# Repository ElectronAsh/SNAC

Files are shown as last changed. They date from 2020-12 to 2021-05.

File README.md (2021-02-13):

# SNAC
Accessory converter for MiSTer, by blue212

Serial Native Accessory Converter

SNAC is general purpose level shifter for use with MiSTer. It can be used to power 5v devices and it will safely convert any logic between the 3v3(MiSTer) and 5 device. It will be used mostly for 5v controllers and other peripherals.

The SNAC connects to the User port(formerly Serial I/O port) of the IO board on Mister. I recommend a male to female usb3 extension cable between them.

The SNAC is available in 2 versions the only difference being the connector on the controller side(USB3 or HDMI). Various adapters can then be plugged into that connector. I made various adapter PCCBs for use with the USB3 verrsion.

Becasue the SNAC connects to the User port the peripheral connects to the GPIO of the MiSTer, this bypasses all layers the normal usb controllers use. So it's very much like having a controller port for the original system. One benefit of this is that most weird peripherals should work with their cores(like Lightguns etc) which most normal usb converters either don't or can't do. One downside to bypassing the layers is the you can't controle the OSD.

*A mod to the IO board is needed if you want to use SEGA peripherals. A possible IO board revision in the future may fix this requirement.

-TODO detail the needed mod

-Updates

Changed the partslist to use a different part for the male USB connector.

Uxcell a19032000ux0260 instead of Wuerth 692112030100

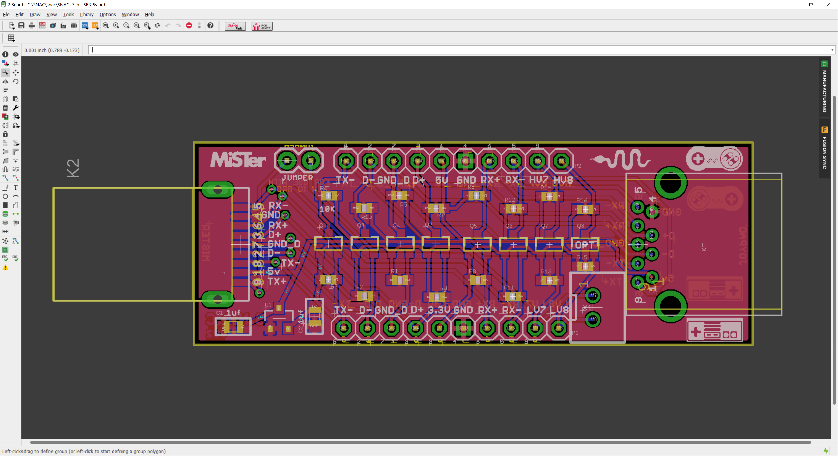
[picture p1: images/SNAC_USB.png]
SNAC to "USB"


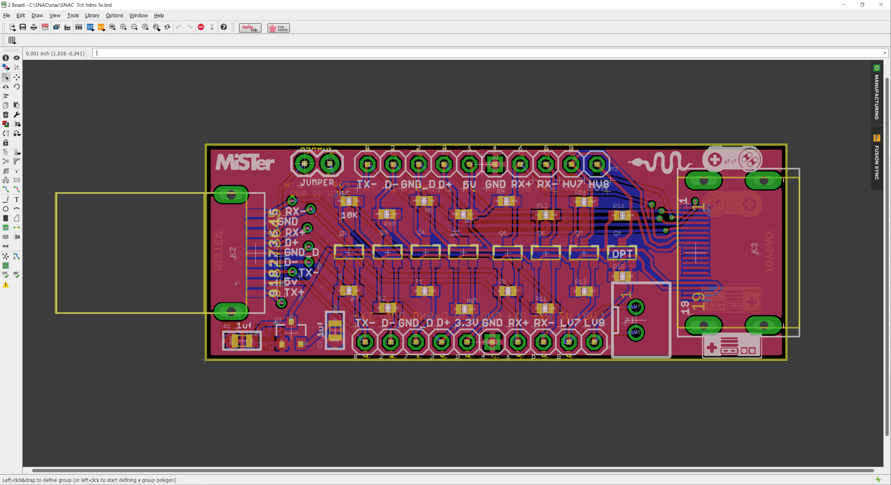
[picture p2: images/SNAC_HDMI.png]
SNAC to "HDMI"


Combined SNES versions, and SMS DB9 version added by ElectronAsh.

#Both SNES versions, and the SMS DB9 version are UNTESTED.
Please do not build until they are confirmed working.

Version with JST XH for the USER IO connection, and PCB meant for a specific housing.
You can find the housing on eBay, using the search term "enclosure 90x70x28mm"

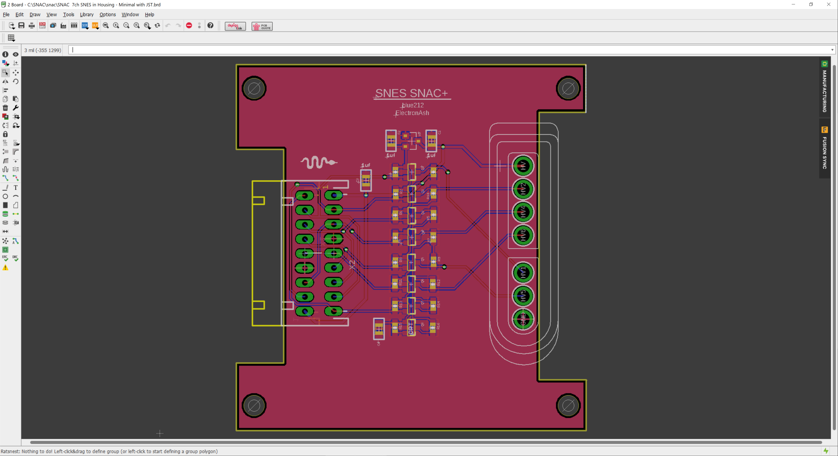
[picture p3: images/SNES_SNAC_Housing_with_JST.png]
SNAC with SNES Socket


The 3D Glasses driver circuit is from e-panorama...
<https://www.epanorama.net/circuits/sega3d.html>

The circuit has been tested on the SMS core now, but it needs a charge pump circuit added, to boost the LCD drive voltage to around 10 Volts.
Without that, the LCDs don't darken enough, and the ghosting is quite severe.

I tested the circuit by powering the CD4030 chip with 10V from a bench PSU. 
(That should ONLY be done if you completely isolate that 10V from the 5V pin on the USER PORT, otherwise it will damage the DE10 Nano.)

EDIT: A charge pump circuit has been added to both the DB9 and dongle version of the 3D Glasses adapter now.
This is currently UNTESTED until more PCBs arrive.

The dongle was tested with the Asus VR-100G LCD shutter glasses, and a JVC monitor.
The frequency of the oscillator that drives the LCDs doesn't seem to have any particular sweet spot for reduction ghosting, but the circuit generally works fine.

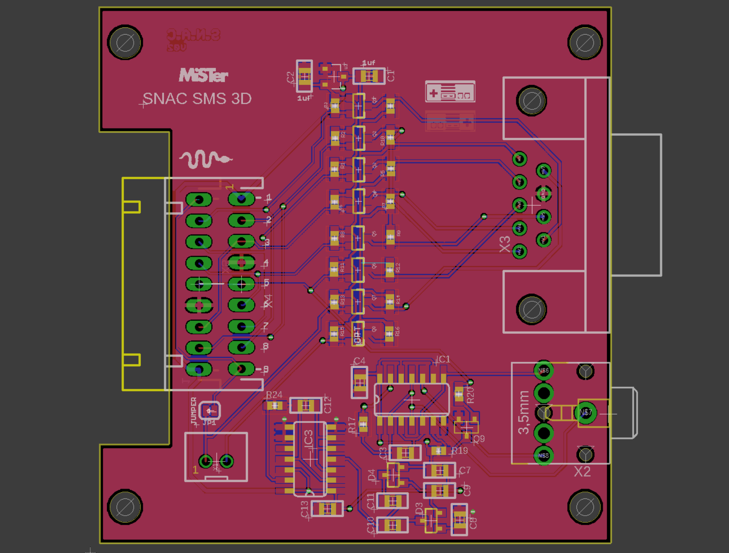
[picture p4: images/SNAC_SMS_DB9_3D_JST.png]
SNAC to SMS DB9 with 3D Glasses driver, JST version


The standalone dongle version of the 3D Glasses driver is for people who don't mind using the SMS core with a USB joypad, and just want the 3D glasses option.
(in which case, both SMS buttons will obviously work fine when mapping from a USB joypad, or USB keyboard.)

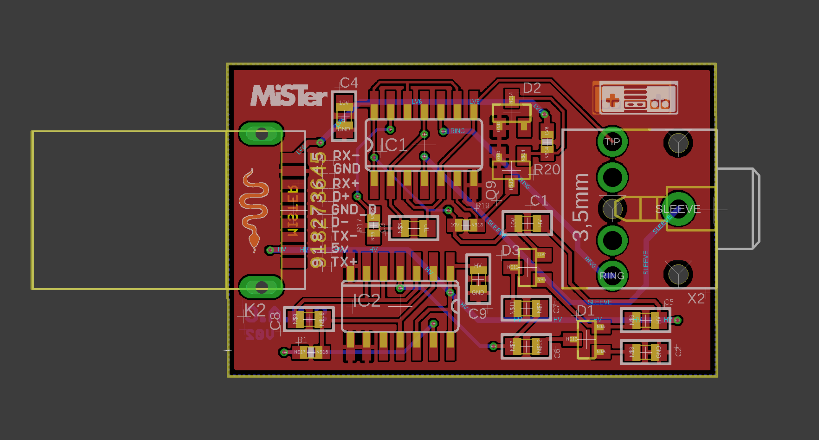
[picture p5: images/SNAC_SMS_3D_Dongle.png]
SNAC to SMS 3D Glasses driver, separate dongle


I updated the SMS core repo on my github with a new menu options (in the Input section) for SNAC-Only, 3D-Only, or SNAC+3D.

<https://github.com/ElectronAsh/SMS_MiSTer/blob/f2dcc660f143cf5afca576f203ca9adbdb81673e/SMS.sv#L199>

One caveat of the 3D mode is that the signal normally used for the Button 2 input from the SMS joypad is used to control the 3D glasses.
So Button 2 won't work in games when 3D glasses mode is enabled.

This also means the option for the "Pause Button Combo" won't work either via SNAC (real SMS joypad) with 3D glasses mode enabled, and the Pause option will be greyed out in the OSD.
(But you can still use the Pause button mapping from a USB joypad.)

AFAIK, SMS Light Gun support should still work via the SNAC adapter with 3D Glasses enabled, but this is currently UNTESTED.
I believe Missile Command 3-D is one of the few SMS games to support 3D Glasses and the Light Gun at the same time.

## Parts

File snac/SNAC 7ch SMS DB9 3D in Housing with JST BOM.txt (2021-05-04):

digiPartlist exported from C:/SNAC/snac/SNAC  7ch SMS DB9 3D in Housing with JST.sch at 16/04/2021 22:44

Part Value                          Device                         Package                     Description 
C1   1uf                            C_0805                         C0805                       NON-POLARIZED CAP	                    digikey 732-7625-1-ND
C2   1uf                            C_0805                         C0805                       NON-POLARIZED CAP	                    digikey 732-7625-1-ND
C3   47nF                           C_0805                         C0805                       NON-POLARIZED CAP	                    digikey 399-C0805C473K2RECAUTOCT-ND
C4   22uF                           C_0805                         C0805                       NON-POLARIZED CAP                        digikey 399-4696-1-ND‎
C5   100uF                          C-EUC1812                      C1812                       CAPACITOR, European symbol               digikey ‎445-7743-1-ND‎
C6   100uF                          C-EUC1812                      C1812                       CAPACITOR, European symbol               digikey ‎445-7743-1-ND‎
C13  22uF                           C_0805                         C0805                       NON-POLARIZED CAP                        digikey 399-4696-1-ND‎
D1   MBRA160T3G‎                     MBRA160T3G‎                     SMA                         Surface Mount Schottky Power Rectifier   digikey MBRA160T3GOSCT-ND
IC1  4030D                          4030D                          SO14                        Quad XOR                                 digikey 296-14263-5-ND
IC2  MAX660CPACS                    MAX660CPACS                    SO08                        Charge-pump VOLTAGE CONVERTER            digikey MAX660MX/NOPBCT-ND
Q1   BSS138                         MOSFET-NCHANNELSMD             SOT23-3                                                              digikey BSS138LCT-ND
Q2   BSS138                         MOSFET-NCHANNELSMD             SOT23-3                                                              digikey BSS138LCT-ND
Q3   BSS138                         MOSFET-NCHANNELSMD             SOT23-3                                                              digikey BSS138LCT-ND
Q4   BSS138                         MOSFET-NCHANNELSMD             SOT23-3                                                              digikey BSS138LCT-ND
Q5   BSS138                         MOSFET-NCHANNELSMD             SOT23-3                                                              digikey BSS138LCT-ND
Q6   BSS138                         MOSFET-NCHANNELSMD             SOT23-3                                                              digikey BSS138LCT-ND
Q7   BSS138                         MOSFET-NCHANNELSMD             SOT23-3                                                              digikey BSS138LCT-ND
Q9   BC849SMD                       BC849SMD                       SOT23-BEC                   NPN Transistor                           digikey BC847C-TPCT-ND
R1   10K                            RESISTOR0603-RES               0603-RES                    Resistor                                 digikey RMCF0603FT10K0CT-ND‎
R2   10K                            RESISTOR0603-RES               0603-RES                    Resistor                                 digikey RMCF0603FT10K0CT-ND‎
R3   10K                            RESISTOR0603-RES               0603-RES                    Resistor                                 digikey RMCF0603FT10K0CT-ND
R4   10K                            RESISTOR0603-RES               0603-RES                    Resistor                                 digikey RMCF0603FT10K0CT-ND
R5   10K                            RESISTOR0603-RES               0603-RES                    Resistor                                 digikey RMCF0603FT10K0CT-ND
R6   10K                            RESISTOR0603-RES               0603-RES                    Resistor                                 digikey RMCF0603FT10K0CT-ND
R7   10K                            RESISTOR0603-RES               0603-RES                    Resistor                                 digikey RMCF0603FT10K0CT-ND
R8   10K                            RESISTOR0603-RES               0603-RES                    Resistor                                 digikey RMCF0603FT10K0CT-ND
R9   10K                            RESISTOR0603-RES               0603-RES                    Resistor                                 digikey RMCF0603FT10K0CT-ND
R10  10K                            RESISTOR0603-RES               0603-RES                    Resistor                                 digikey RMCF0603FT10K0CT-ND
R11  10K                            RESISTOR0603-RES               0603-RES                    Resistor                                 digikey RMCF0603FT10K0CT-ND
R12  10K                            RESISTOR0603-RES               0603-RES                    Resistor                                 digikey RMCF0603FT10K0CT-ND
R15  10K                            RESISTOR0603-RES               0603-RES                    Resistor                                 digikey RMCF0603FT10K0CT-ND
R16  10K                            RESISTOR0603-RES               0603-RES                    Resistor                                 digikey RMCF0603FT10K0CT-ND
R17  75K                            RESISTOR0603-RES               0603-RES                    Resistor                                 digikey RMCF0603JT75K0CT-ND
R18  10K                            RESISTOR0603-RES               0603-RES                    Resistor                                 digikey RMCF0603FT10K0CT-ND
R19  10K                            RESISTOR0603-RES               0603-RES                    Resistor                                 digikey RMCF0603FT10K0CT-ND
R20  10K                            RESISTOR0603-RES               0603-RES                    Resistor                                 digikey RMCF0603FT10K0CT-ND
U1   AP2127N-3.3TRG1                LDO 3V3                        SOT-23                      Voltage Regulator                        digikey AP2127N-3.3TRG1DICT-ND
X2   STEREOJACK                     STEREOJACK                     STX3100                     MIC/HEADPHONE JACK                       digikey CP1-3523N-ND
X4   JST-XH-09-PIN-LONG-PAD         JST-XH-09-PIN-LONG-PAD         JST-XH-09-PACKAGE-LONG-PAD  JST XH Connector 9 Pin                   digikey 455-2224-ND
X5   JST-XH-09-PIN-LONG-PAD         JST-XH-09-PIN-LONG-PAD         JST-XH-09-PACKAGE-LONG-PAD  JST XH Connector 9 Pin                   (only need one 9-pin JST)
X6   D-SUB9-H5M09RA                 D-SUB9-H5M09RA                 H5M09RA                     D-Subminiature Connector                 digikey 609-5183-ND

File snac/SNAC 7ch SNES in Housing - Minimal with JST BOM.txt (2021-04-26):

Partlist exported from C:/SNAC/snac/SNAC  7ch SNES in Housing - Minimal with JST.sch at 26/04/2021 04:11

Part     Value                          Device                         Package                    Description            AVAILABILITY DESCRIPTION MF   MP      PACKAGE PRICE 
C1       1uf                            C_0805                         C0805                      NON-POLARIZED CAP                                                          
C2       1uf                            C_0805                         C0805                      NON-POLARIZED CAP                                                          
C3       100nF                          C_0805                         C0805                      NON-POLARIZED CAP                                                          
Q1       BSS138                         MOSFET-NCHANNELSMD             SOT23-3                                                                                               
Q2       BSS138                         MOSFET-NCHANNELSMD             SOT23-3                                                                                               
Q3       BSS138                         MOSFET-NCHANNELSMD             SOT23-3                                                                                               
Q4       BSS138                         MOSFET-NCHANNELSMD             SOT23-3                                                                                               
Q5       BSS138                         MOSFET-NCHANNELSMD             SOT23-3                                                                                               
Q6       BSS138                         MOSFET-NCHANNELSMD             SOT23-3                                                                                               
Q7       BSS138                         MOSFET-NCHANNELSMD             SOT23-3                                                                                               
Q8       BSS138                         MOSFET-NCHANNELSMD             SOT23-3                                                                                               
R1       10K                            RESISTOR0603-RES               0603-RES                   Resistor                                                                   
R2       10K                            RESISTOR0603-RES               0603-RES                   Resistor                                                                   
R3       10K                            RESISTOR0603-RES               0603-RES                   Resistor                                                                   
R4       10K                            RESISTOR0603-RES               0603-RES                   Resistor                                                                   
R5       10K                            RESISTOR0603-RES               0603-RES                   Resistor                                                                   
R6       10K                            RESISTOR0603-RES               0603-RES                   Resistor                                                                   
R7       10K                            RESISTOR0603-RES               0603-RES                   Resistor                                                                   
R8       10K                            RESISTOR0603-RES               0603-RES                   Resistor                                                                   
R9       10K                            RESISTOR0603-RES               0603-RES                   Resistor                                                                   
R10      10K                            RESISTOR0603-RES               0603-RES                   Resistor                                                                   
R11      10K                            RESISTOR0603-RES               0603-RES                   Resistor                                                                   
R12      10K                            RESISTOR0603-RES               0603-RES                   Resistor                                                                   
R13      10K                            RESISTOR0603-RES               0603-RES                   Resistor                                                                   
R14      10K                            RESISTOR0603-RES               0603-RES                   Resistor                                                                   
R15      10K                            RESISTOR0603-RES               0603-RES                   Resistor                                                                   
R16      10K                            RESISTOR0603-RES               0603-RES                   Resistor                                                                   
SNES_CON SNESCONN                       SNESCONN                       SNESCONN                                                                                              
U1       PMIC-LDO-XC6206P332MR-G(SOT23) PMIC-LDO-XC6206P332MR-G(SOT23) SOT-23                     310030099              Unavailable   SMD PMIC    LDO  Vin 6V  3.3V    200mA
X1       JST-XH-09-PIN-LONG-PAD         JST-XH-09-PIN-LONG-PAD         JST-XH-09-PACKAGE-LONG-PAD JST XH Connector 2 Pin                                                     
X2       JST-XH-09-PIN-LONG-PAD         JST-XH-09-PIN-LONG-PAD         JST-XH-09-PACKAGE-LONG-PAD JST XH Connector 2 Pin

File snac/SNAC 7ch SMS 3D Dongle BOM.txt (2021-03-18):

Partlist exported from C:/SNAC/snac/SNAC  7ch SMS 3D Dongle.sch at 09/12/2020 16:54

Part Value        Device           Package      Description
R17  75K          RESISTOR0603-RES 0603-RES     Resistor                                 digikey RMCF0603FT75K0
R1   10K          RESISTOR0603-RES 0603-RES     Resistor                                 digikey RMCF0603JT10K0CT-ND
R19  10K          RESISTOR0603-RES 0603-RES     Resistor                                 digikey RMCF0603JT10K0CT-ND
R20  10K          RESISTOR0603-RES 0603-RES     Resistor                                 digikey RMCF0603JT10K0CT-ND
C1   100uF        C_1210           C1210        NON-POLARIZED CAP 16V                    digikey EMK325ABJ107MM-P
C2   100uF        C_1210           C1210        NON-POLARIZED CAP 16V                    digikey EMK325ABJ107MM-P
C3   10nF         C_0805           C0805        NON-POLARIZED CAP                        digikey C0805X103K1RAC3316CT-ND
C4   22uF         C_0805           C0805        NON-POLARIZED CAP                        digikey 399-4696-1-ND
C5   22uF         C_0805           C0805        NON-POLARIZED CAP                        digikey 399-4696-1-ND
D1   MBRA340T3    MBRA340T3        SMA          Schottky Diode                           digikey 2156-MBRA340T3G-OS-ND
IC1  MAX660MX     MAX660           SO8          Charge Pump IC                           digikey MAX660MX/NOPBCT-ND
IC2  4030D        4030D            SO14         Quad XOR                                 digikey 296-14263-5-ND
Q9   BC849SMD     BC849SMD         SOT23-BEC    NPN Transistor                           digikey BC847C-TPCT-ND
X2   STEREOJACK   STEREOJACK       STX3100      MIC/HEADPHONE JACK                       digikey CP1-3523N-ND
K2   692112030100 692112030100     692112030100 WR-COM  USB 3.0 SMT PLUG WITH CLIPTYPE A digikey 732-3157-ND

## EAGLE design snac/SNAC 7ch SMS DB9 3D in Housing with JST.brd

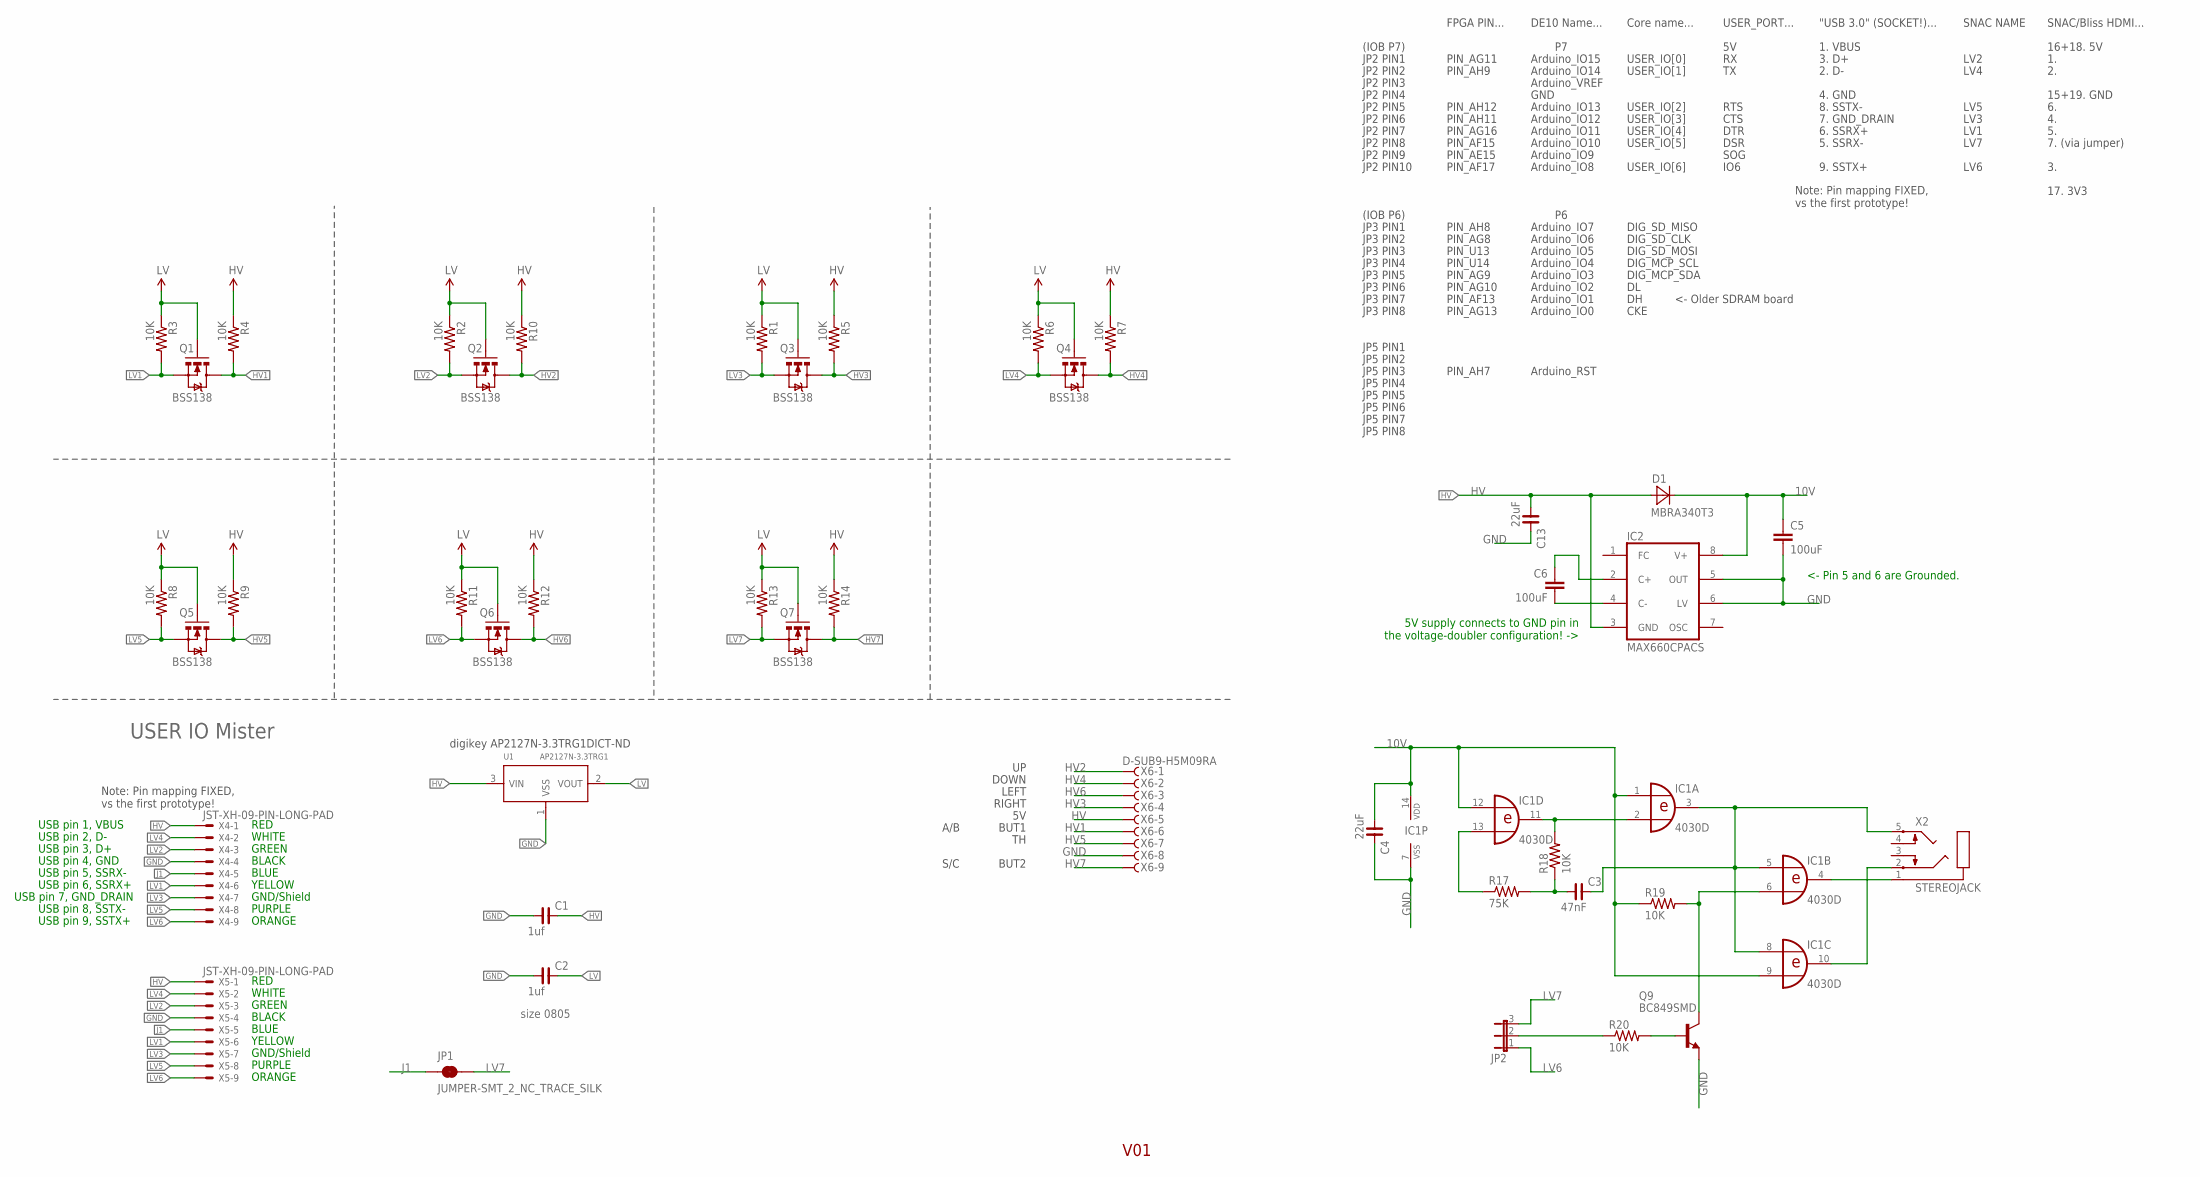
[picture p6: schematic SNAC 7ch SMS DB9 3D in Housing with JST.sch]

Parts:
C1, C2: 1uf; C0805
C3: 47nF; C0805
C4, C13: 22uF; C0805
C5, C6: 100uF; C1812
D1: MBRA340T3; SMA
IC1: 4030D; SO14
IC2: MAX660CPACS; SO08
JP1: JUMPER-SMT_2_NC_TRACE_SILK; SMT-JUMPER_2_NC_TRACE_SILK
JP2: JP2E; JP2
Q1, Q2, Q3, Q4, Q5, Q6, Q7: BSS138; SOT23-3
Q9: BC849SMD; SOT23-BEC
R1, R2, R3, R4, R5, R6, R7, R8, R9, R10, R11, R12, R13, R14, R18, R19, R20: 10K; 0603-RES
R17: 75K; 0603-RES
U1: AP2127N-3.3TRG1; SOT-23
X2: STEREOJACK; STX3100
X4, X5: JST-XH-09-PIN-LONG-PAD; JST-XH-09-PACKAGE-LONG-PAD
X6: D-SUB9-H5M09RA; H5M09RA

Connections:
10V: C4.1, C5.1, D1.C, IC1.1 (I0), IC1.9 (I1), IC1.12 (I0), IC1.14 (VDD), IC2.8 (V+), R19.1
GND: C1.1, C2.1, C4.2, C5.2, C13.2, IC1.7 (VSS), IC2.5 (OUT), IC2.6 (LV), Q9.E, U1.1 (VSS), X4.4, X5.4, X6.8
HV: C1.2, C13.1, D1.A, IC2.3 (GND), R4.1, R5.1, R7.1, R9.1, R10.1, R12.1, R14.1, U1.3 (VIN), X4.1, X5.1, X6.5
HV1: Q1.3 (D), R4.2, X6.6
HV2: Q2.3 (D), R10.2, X6.1
HV3: Q3.3 (D), R5.2, X6.4
HV4: Q4.3 (D), R7.2, X6.2
HV5: Q5.3 (D), R9.2, X6.7
HV6: Q6.3 (D), R12.2, X6.3
HV7: Q7.3 (D), R14.2, X6.9
J1: JP1.1, X4.5, X5.5
LV: C2.2, Q1.1 (G), Q2.1 (G), Q3.1 (G), Q4.1 (G), Q5.1 (G), Q6.1 (G), Q7.1 (G), R1.1, R2.1, R3.1, R6.1, R8.1, R11.1, R13.1, U1.2 (VOUT)
LV1: Q1.2 (S), R3.2, X4.6, X5.6
LV2: Q2.2 (S), R2.2, X4.3, X5.3
LV3: Q3.2 (S), R1.2, X4.7, X5.7
LV4: Q4.2 (S), R6.2, X4.2, X5.2
LV5: Q5.2 (S), R8.2, X4.8, X5.8
LV6: JP2.1, Q6.2 (S), R11.2, X4.9, X5.9
LV7: JP1.2, JP2.3, Q7.2 (S), R13.2
unnamed: IC1.2 (I1), IC1.11 (O), R18.2
unnamed: C3.2, IC1.3 (O), IC1.5 (I0), IC1.8 (I0), X2.5
unnamed: IC1.4 (O), X2.1
unnamed: IC1.10 (O), X2.2
unnamed: IC1.13 (I1), R17.1
unnamed: C6.1, IC2.2 (C+)
unnamed: IC1.6 (I1), Q9.C, R19.2
unnamed: Q9.B, R20.2
unnamed: C6.2, IC2.4 (C-)
unnamed: C3.1, R17.2, R18.1
unnamed: JP2.2, R20.1

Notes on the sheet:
V01
size 0805
DOWN
LEFT
RIGHT
BUT1
BUT2
A/B
S/C
USER IO Mister
USB pin 2, D-
USB pin 3, D+
USB pin 5, SSRX-
USB pin 6, SSRX+
USB pin 7, GND_DRAIN
USB pin 1, VBUS
USB pin 8, SSTX-
USB pin 9, SSTX+
USB pin 4, GND
RED
WHITE
GREEN
BLACK
BLUE
YELLOW
GND/Shield
PURPLE
ORANGE
5V supply connects to GND pin in the voltage-doubler configuration! ->
<- Pin 5 and 6 are Grounded.
digikey AP2127N-3.3TRG1DICT-ND
JP2 PIN1
PIN_AH7
JP2 PIN2
JP2 PIN3
JP2 PIN4
JP2 PIN5
JP2 PIN6
JP2 PIN7
JP2 PIN8

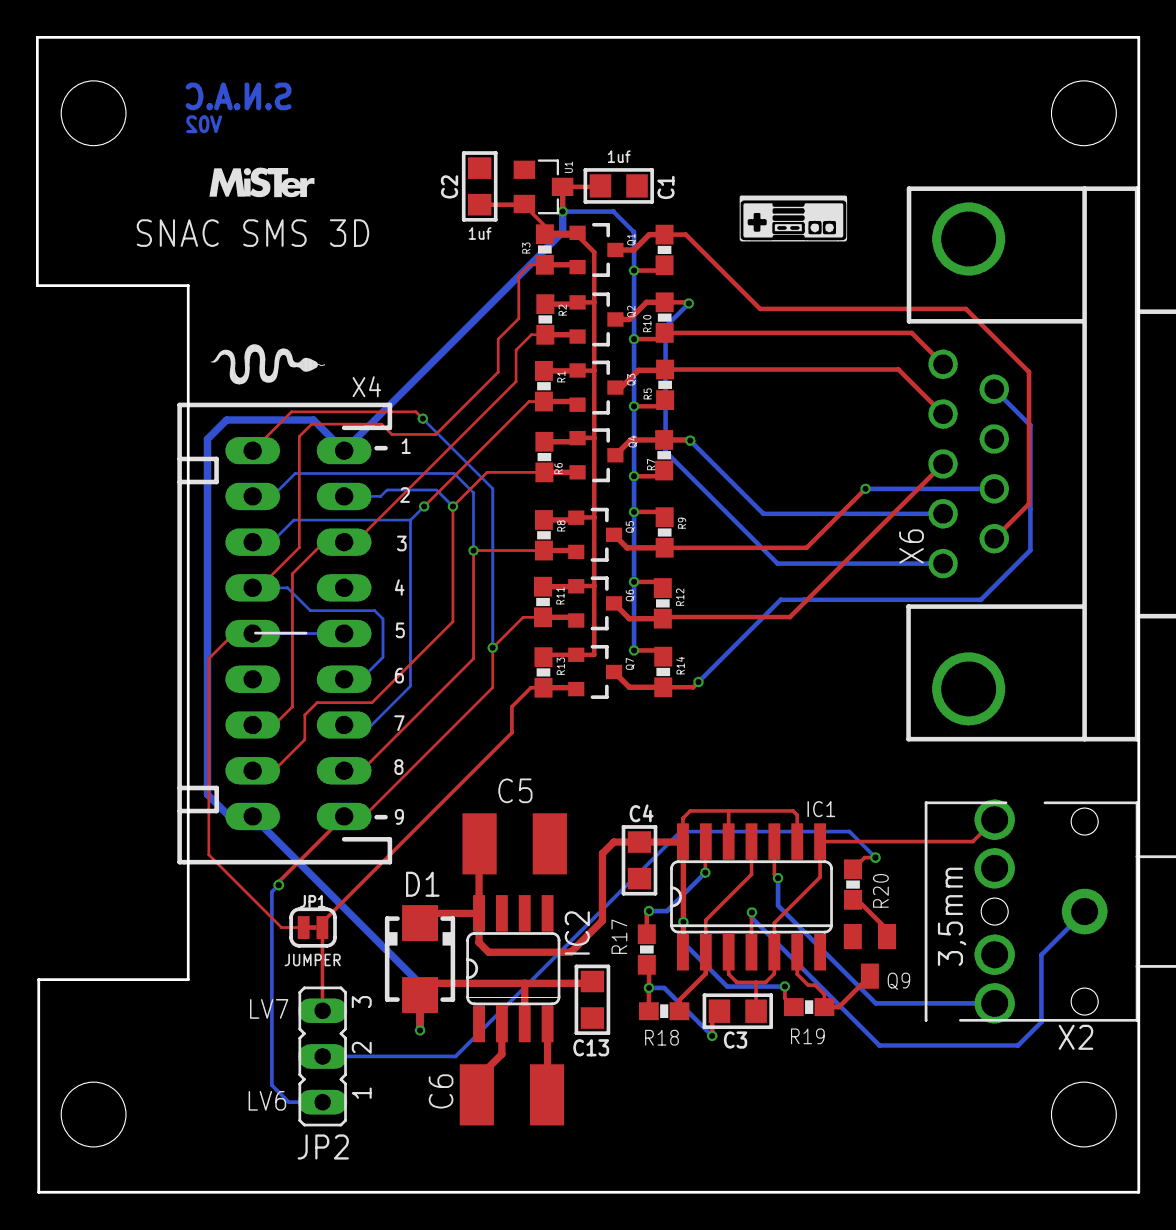
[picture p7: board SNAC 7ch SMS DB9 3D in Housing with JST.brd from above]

Board: 2 copper layers, 61.2 x 64.2 mm, 43 parts (1 on the bottom side), 30 nets.

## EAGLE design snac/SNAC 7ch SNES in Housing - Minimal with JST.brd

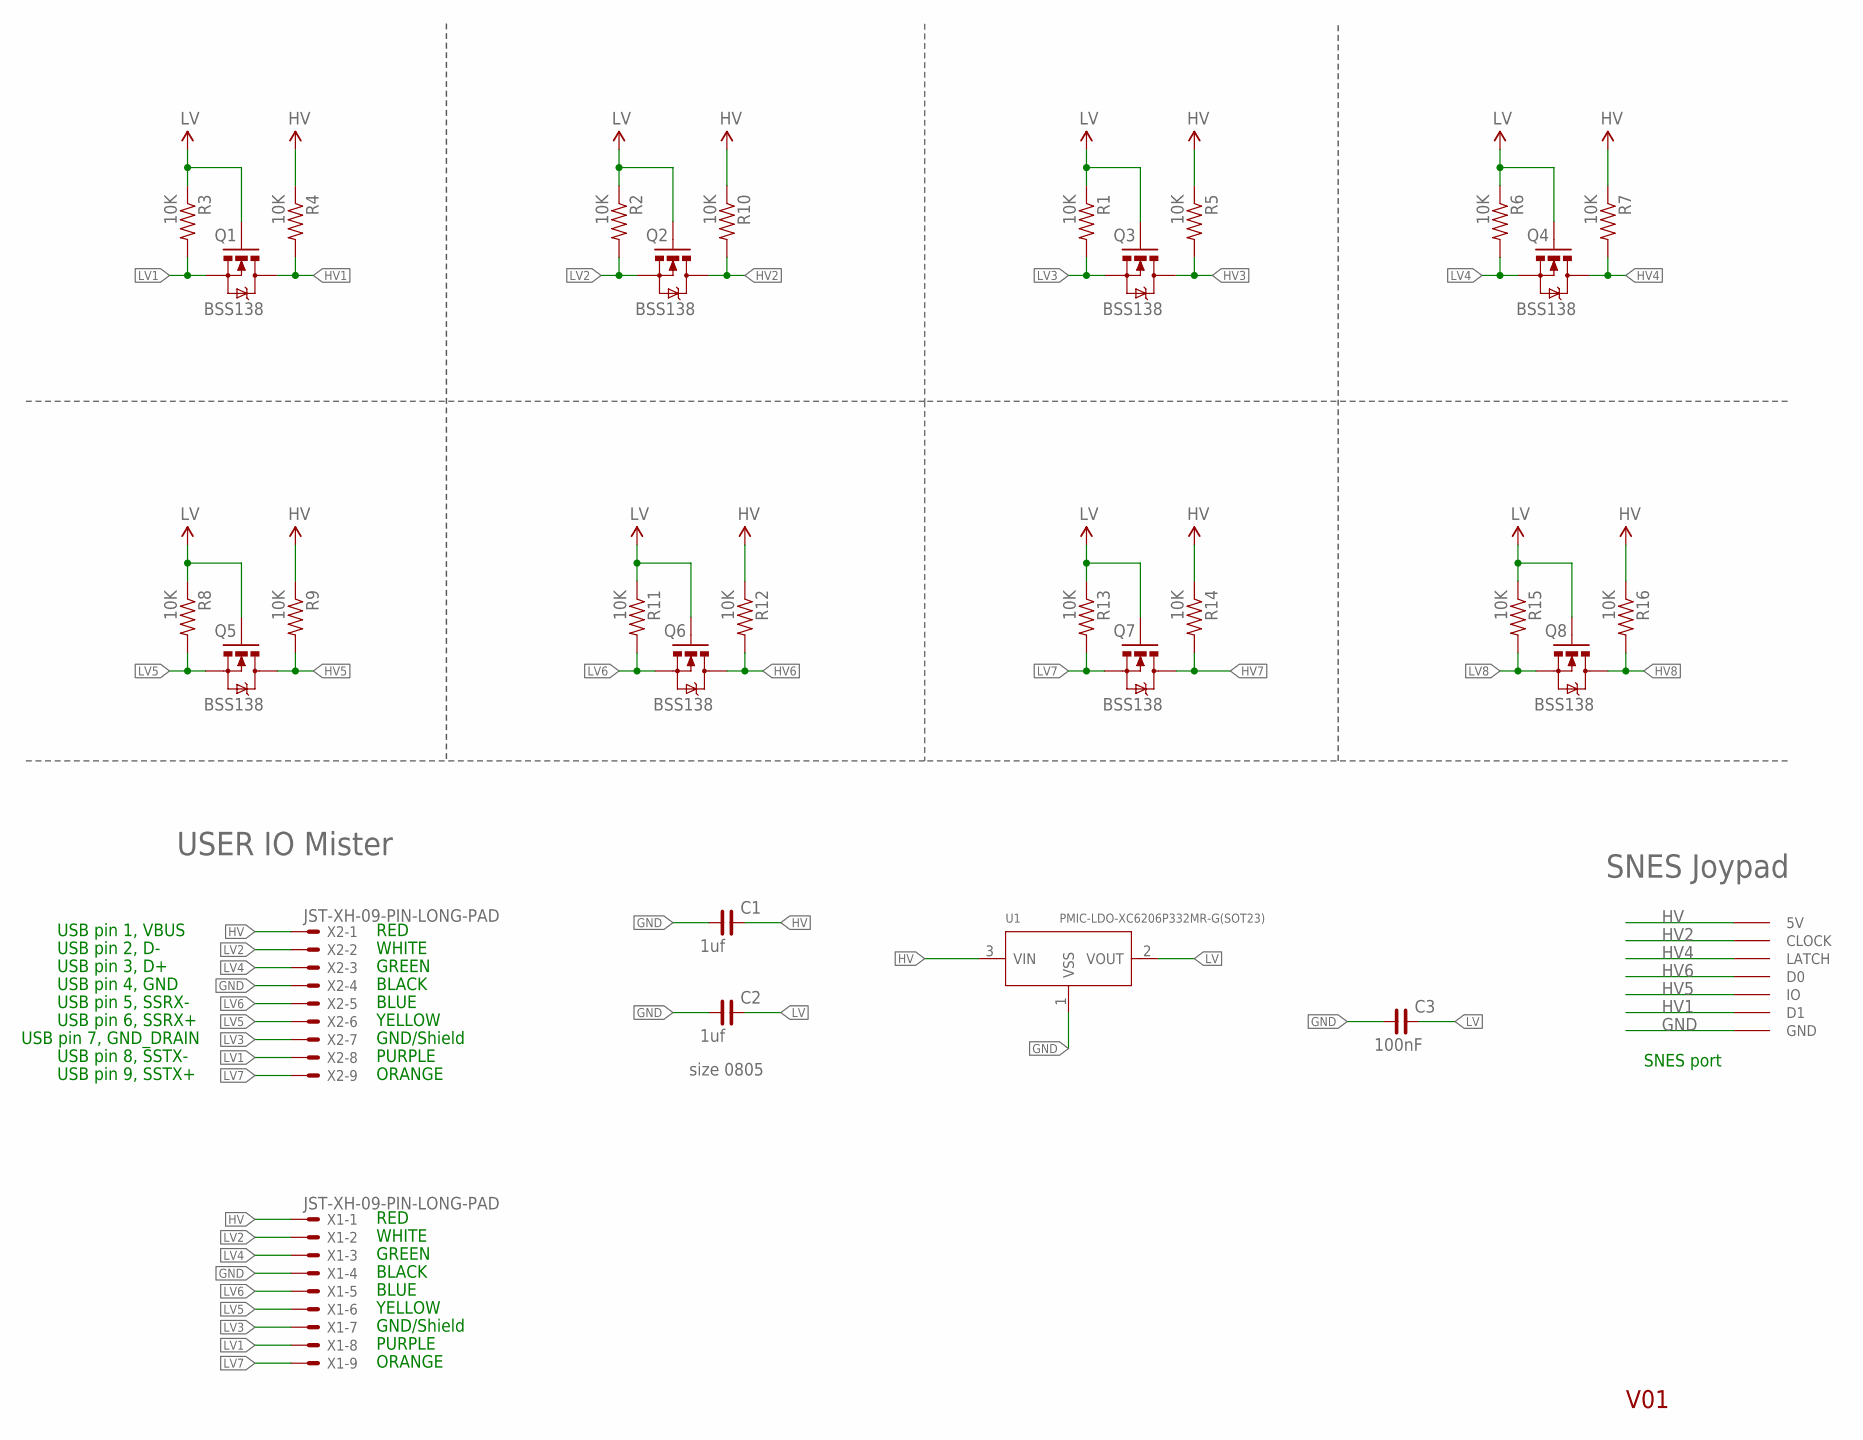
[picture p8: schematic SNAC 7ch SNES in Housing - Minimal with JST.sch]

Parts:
C1, C2: 1uf; C0805
C3: 100nF; C0805
Q1, Q2, Q3, Q4, Q5, Q6, Q7, Q8: BSS138; SOT23-3
R1, R2, R3, R4, R5, R6, R7, R8, R9, R10, R11, R12, R13, R14, R15, R16: 10K; 0603-RES
SNES_CON: SNESCONN
U1: PMIC-LDO-XC6206P332MR-G(SOT23); SOT-23
X1, X2: JST-XH-09-PIN-LONG-PAD; JST-XH-09-PACKAGE-LONG-PAD

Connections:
GND: C1.1, C2.1, C3.1, SNES_CON.GND, U1.1 (VSS), X1.4, X2.4
HV: C1.2, R4.1, R5.1, R7.1, R9.1, R10.1, R12.1, R14.1, R16.1, SNES_CON.5V, U1.3 (VIN), X1.1, X2.1
HV1: Q1.3 (D), R4.2, SNES_CON.D1
HV2: Q2.3 (D), R10.2, SNES_CON.CLOCK
HV3: Q3.3 (D), R5.2
HV4: Q4.3 (D), R7.2, SNES_CON.LATCH
HV5: Q5.3 (D), R9.2, SNES_CON.IO
HV6: Q6.3 (D), R12.2, SNES_CON.D0
HV7: Q7.3 (D), R14.2
HV8: Q8.3 (D), R16.2
LV: C2.2, C3.2, Q1.1 (G), Q2.1 (G), Q3.1 (G), Q4.1 (G), Q5.1 (G), Q6.1 (G), Q7.1 (G), Q8.1 (G), R1.1, R2.1, R3.1, R6.1, R8.1, R11.1, R13.1, R15.1, U1.2 (VOUT)
LV1: Q1.2 (S), R3.2, X1.8, X2.8
LV2: Q2.2 (S), R2.2, X1.2, X2.2
LV3: Q3.2 (S), R1.2, X1.7, X2.7
LV4: Q4.2 (S), R6.2, X1.3, X2.3
LV5: Q5.2 (S), R8.2, X1.6, X2.6
LV6: Q6.2 (S), R11.2, X1.5, X2.5
LV7: Q7.2 (S), R13.2, X1.9, X2.9
LV8: Q8.2 (S), R15.2

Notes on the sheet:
V01
USER IO Mister
size 0805
SNES port
SNES Joypad
USB pin 2, D-
USB pin 3, D+
USB pin 5, SSRX-
USB pin 6, SSRX+
USB pin 7, GND_DRAIN
USB pin 1, VBUS
USB pin 8, SSTX-
USB pin 9, SSTX+
USB pin 4, GND
RED
WHITE
GREEN
BLACK
BLUE
YELLOW
GND/Shield
PURPLE
ORANGE

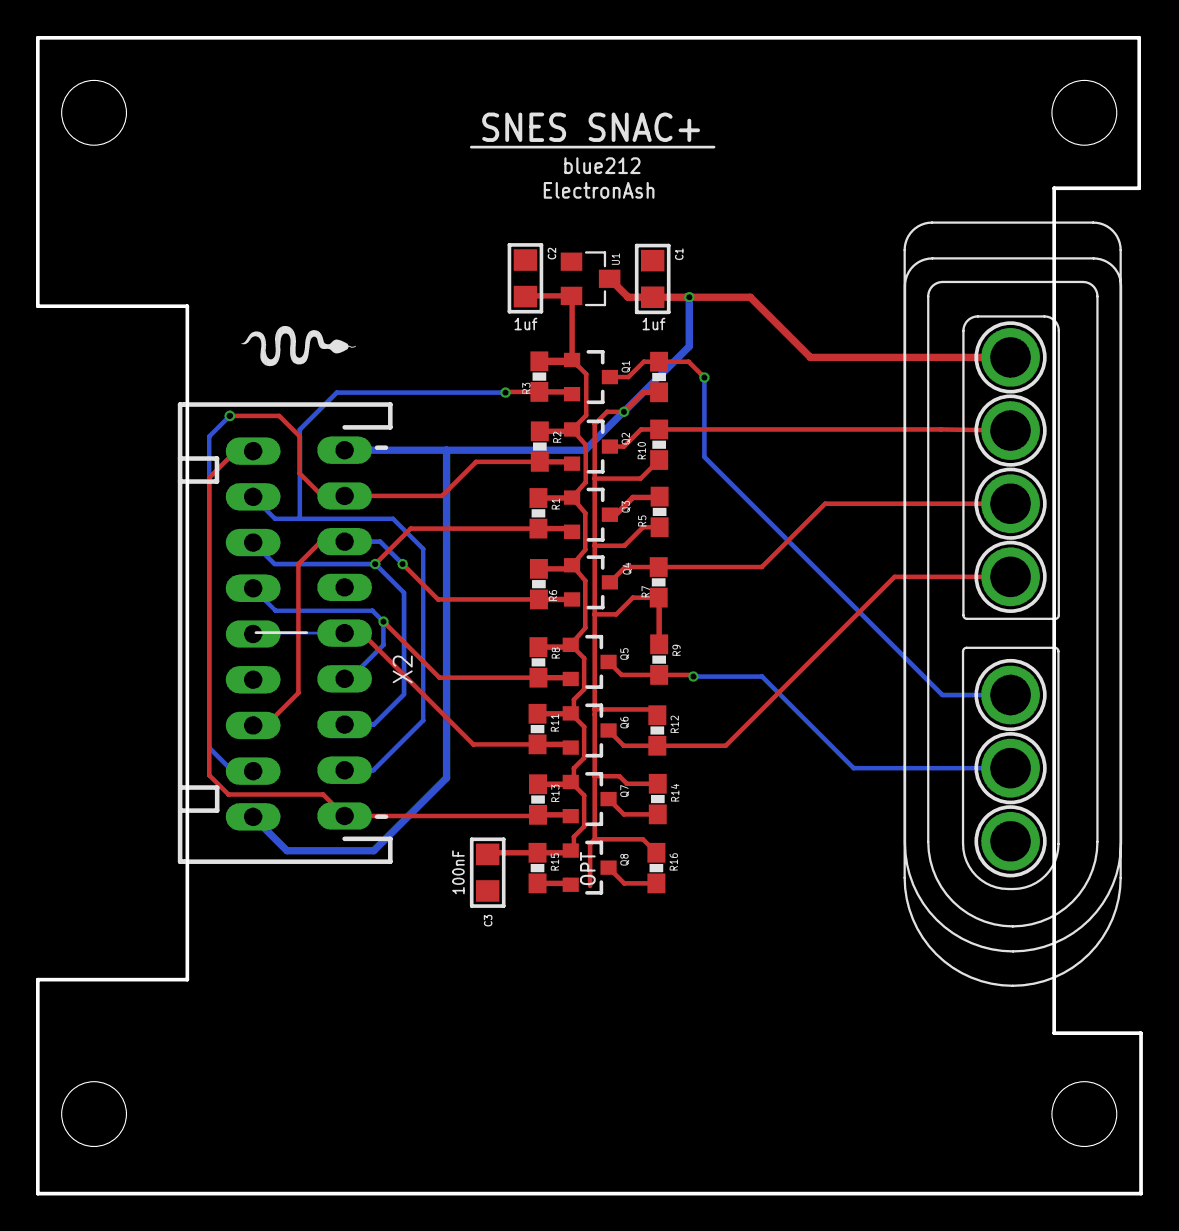
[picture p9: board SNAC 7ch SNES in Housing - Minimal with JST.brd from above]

Board: 2 copper layers, 61.3 x 64.2 mm, 31 parts (1 on the bottom side), 19 nets.

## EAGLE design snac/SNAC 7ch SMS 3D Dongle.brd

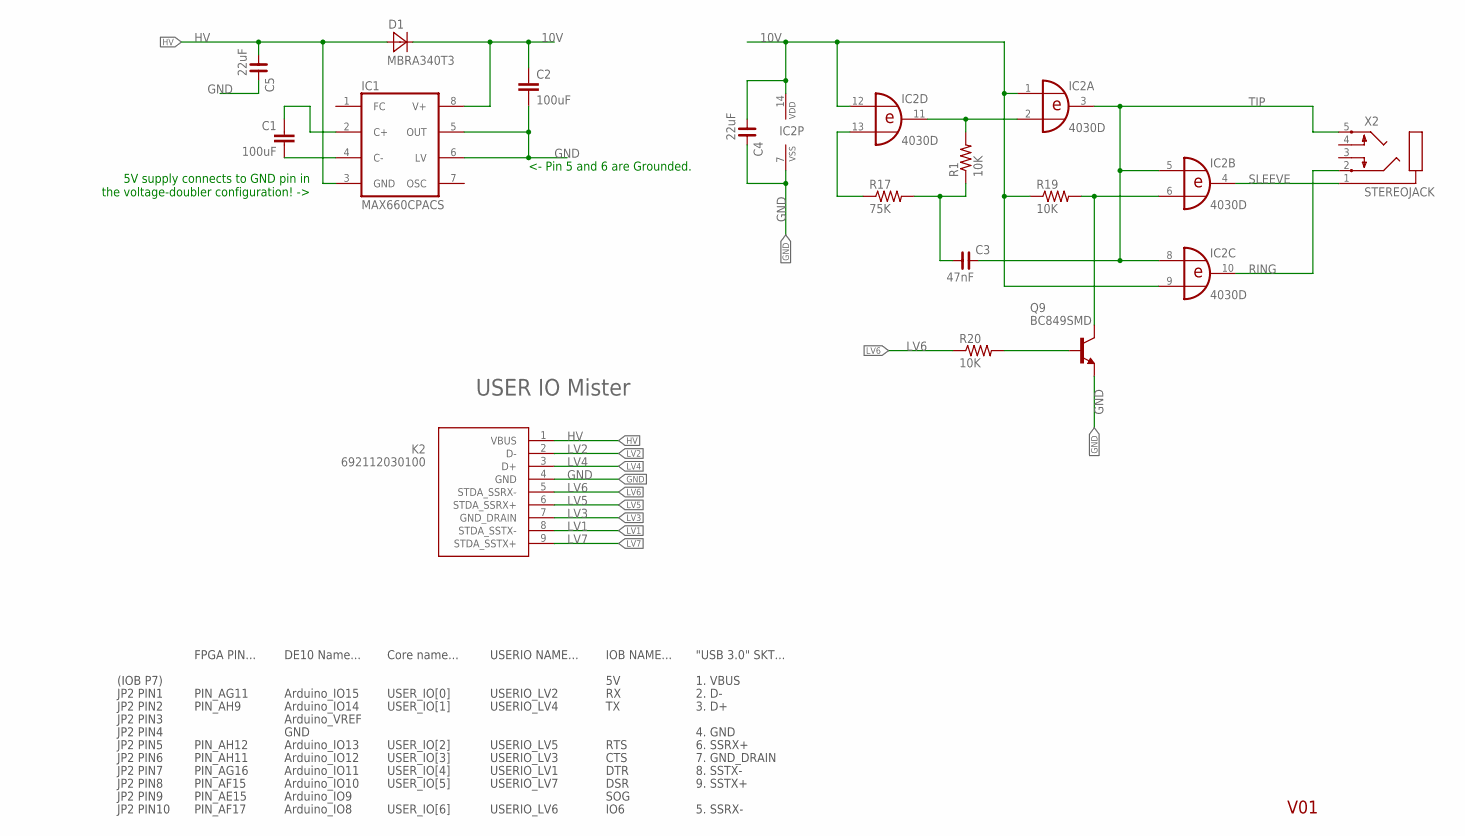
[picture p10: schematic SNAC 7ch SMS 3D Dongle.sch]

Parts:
C1, C2: 100uF; C1210
C3: 47nF; C0805
C4, C5: 22uF; C0805
D1: MBRA340T3; SMA
IC1: MAX660CPACS; SO08
IC2: 4030D; SO14
K2: 692112030100
Q9: BC849SMD; SOT23-BEC
R1, R19, R20: 10K; 0603-RES
R17: 75K; 0603-RES
X2: STEREOJACK; STX3100

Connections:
10V: C2.1, C4.1, D1.C, IC1.8 (V+), IC2.1 (I0), IC2.9 (I1), IC2.12 (I0), IC2.14 (VDD), R19.1
GND: C2.2, C4.2, C5.2, IC1.5 (OUT), IC1.6 (LV), IC2.7 (VSS), K2.4 (GND), Q9.E
HV: C5.1, D1.A, IC1.3 (GND), K2.1 (VBUS)
LV1: K2.8 (STDA_SSTX-)
LV2: K2.2 (D-)
LV3: K2.7 (GND_DRAIN)
LV4: K2.3 (D+)
LV5: K2.6 (STDA_SSRX+)
LV6: K2.5 (STDA_SSRX-), R20.1
LV7: K2.9 (STDA_SSTX+)
unnamed: C3.1, R1.1, R17.2
unnamed: IC2.2 (I1), IC2.11 (O), R1.2
unnamed: IC2.13 (I1), R17.1
unnamed: IC2.6 (I1), Q9.C, R19.2
unnamed: Q9.B, R20.2
unnamed: C1.1, IC1.2 (C+)
unnamed: C1.2, IC1.4 (C-)
RING: IC2.10 (O), X2.2
SLEEVE: IC2.4 (O), X2.1
TIP: C3.2, IC2.3 (O), IC2.5 (I0), IC2.8 (I0), X2.5

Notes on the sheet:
V01
USER IO Mister
Arduino_IO15
Arduino_IO14
Arduino_IO13
Arduino_VREF
Arduino_IO12
Arduino_IO11
Arduino_IO10
Arduino_IO9
Arduino_IO8
RTS
CTS
DTR
DSR
SOG
IO6
IOB NAME...
GND
2. D-
3. D+
4. GND
1. VBUS
5. SSRX-
6. SSRX+
7. GND_DRAIN
8. SSTX-
9. SSTX+
"USB 3.0" SKT...
DE10 Name...
Core name...
USER_IO[6]
USER_IO[5]
USER_IO[4]
USER_IO[3]
USER_IO[2]
USER_IO[1]
USER_IO[0]
JP2 PIN1
USERIO_LV2

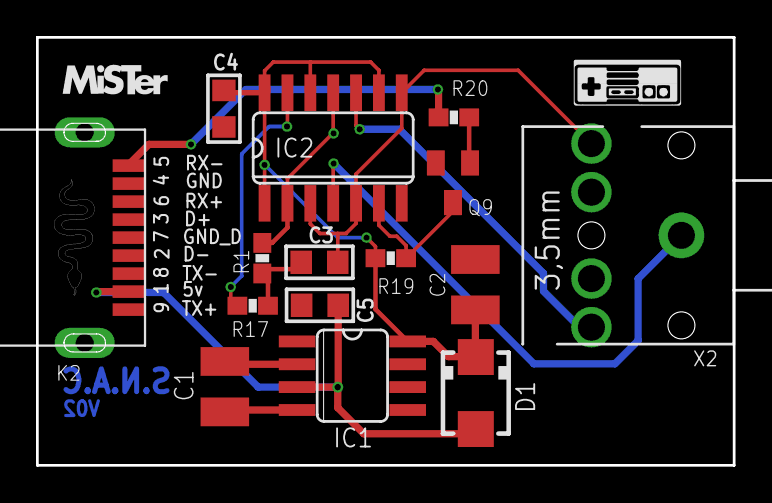
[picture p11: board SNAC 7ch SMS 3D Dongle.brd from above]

Board: 2 copper layers, 38.7 x 23.8 mm, 15 parts (0 on the bottom side), 14 nets.

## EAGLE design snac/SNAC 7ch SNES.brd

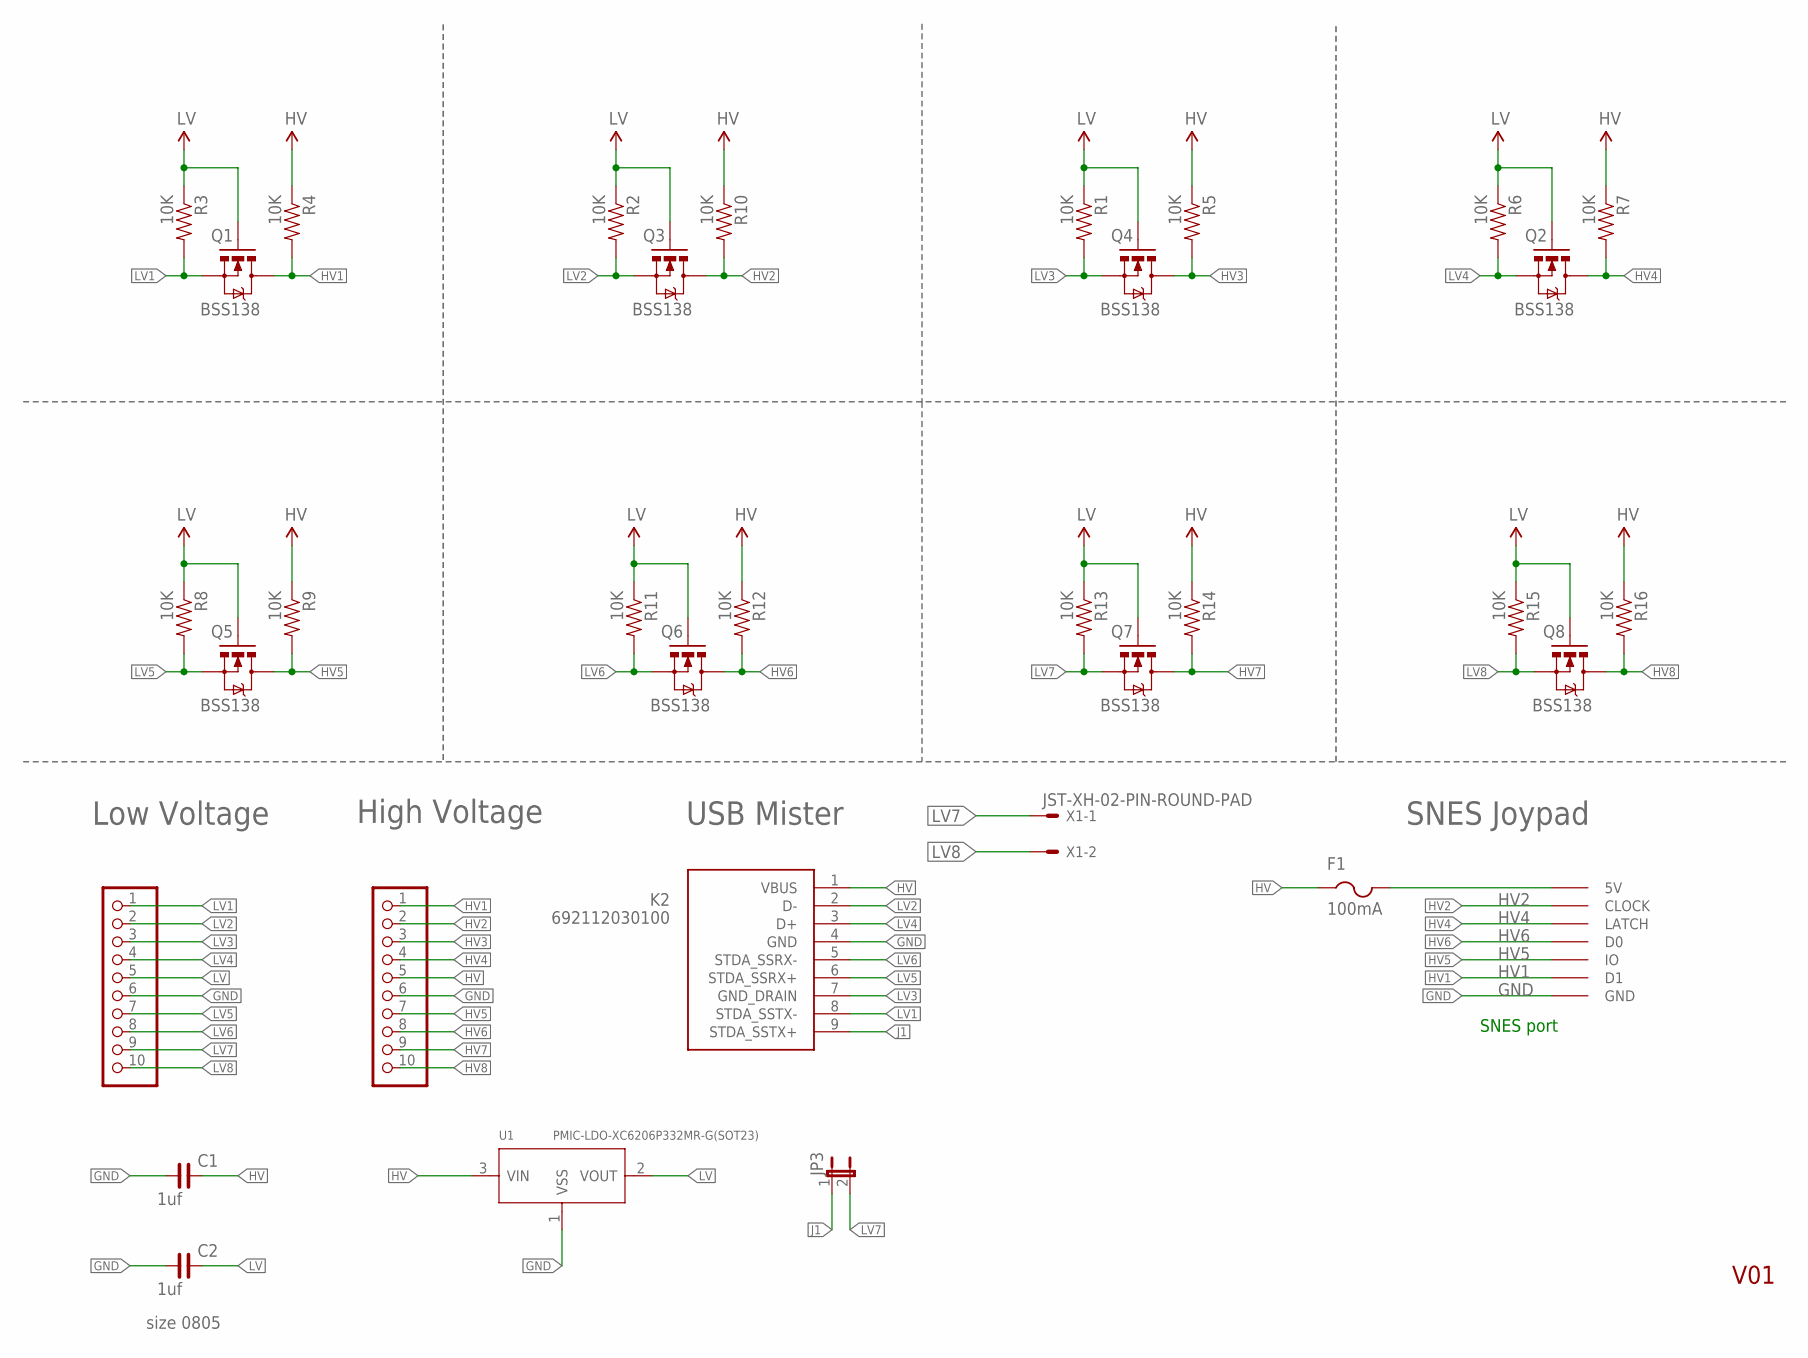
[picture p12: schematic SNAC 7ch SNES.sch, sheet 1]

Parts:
C1, C2: 1uf; C0805
F1: 100mA; R1206
JP1, JP2: PINHD-1X10_2.54-S; 1X10-S
JP3: JUMPER-2PTH; 1X02
K2: 692112030100
Q1, Q2, Q3, Q4, Q5, Q6, Q7, Q8: BSS138; SOT23-3
R1, R2, R3, R4, R5, R6, R7, R8, R9, R10, R11, R12, R13, R14, R15, R16: 10K; 0603-RES
U1: PMIC-LDO-XC6206P332MR-G(SOT23); SOT-23
U$3: SNESCONN
X1: JST-XH-02-PIN-ROUND-PAD; JST-XH-02-PACKAGE-ROUND-PAD

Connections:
GND: C1.1, C2.1, JP1.6, JP2.6, K2.4 (GND), U1.1 (VSS), U$3.GND
HV: C1.2, F1.1, JP2.5, K2.1 (VBUS), R4.1, R5.1, R7.1, R9.1, R10.1, R12.1, R14.1, R16.1, U1.3 (VIN)
HV1: JP2.1, Q1.3 (D), R4.2, U$3.D1
HV2: JP2.2, Q3.3 (D), R10.2, U$3.CLOCK
HV3: JP2.3, Q4.3 (D), R5.2
HV4: JP2.4, Q2.3 (D), R7.2, U$3.LATCH
HV5: JP2.7, Q5.3 (D), R9.2, U$3.IO
HV6: JP2.8, Q6.3 (D), R12.2, U$3.D0
HV7: JP2.9, Q7.3 (D), R14.2
HV8: JP2.10, Q8.3 (D), R16.2
J1: JP3.1, K2.9 (STDA_SSTX+)
LV: C2.2, JP1.5, Q1.1 (G), Q2.1 (G), Q3.1 (G), Q4.1 (G), Q5.1 (G), Q6.1 (G), Q7.1 (G), Q8.1 (G), R1.1, R2.1, R3.1, R6.1, R8.1, R11.1, R13.1, R15.1, U1.2 (VOUT)
LV1: JP1.1, K2.8 (STDA_SSTX-), Q1.2 (S), R3.2
LV2: JP1.2, K2.2 (D-), Q3.2 (S), R2.2
LV3: JP1.3, K2.7 (GND_DRAIN), Q4.2 (S), R1.2
LV4: JP1.4, K2.3 (D+), Q2.2 (S), R6.2
LV5: JP1.7, K2.6 (STDA_SSRX+), Q5.2 (S), R8.2
LV6: JP1.8, K2.5 (STDA_SSRX-), Q6.2 (S), R11.2
LV7: JP1.9, JP3.2, Q7.2 (S), R13.2, X1.1
LV8: JP1.10, Q8.2 (S), R15.2, X1.2
unnamed: F1.2, U$3.5V

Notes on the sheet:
High Voltage
Low Voltage
V01
USB Mister
size 0805
SNES port
SNES Joypad

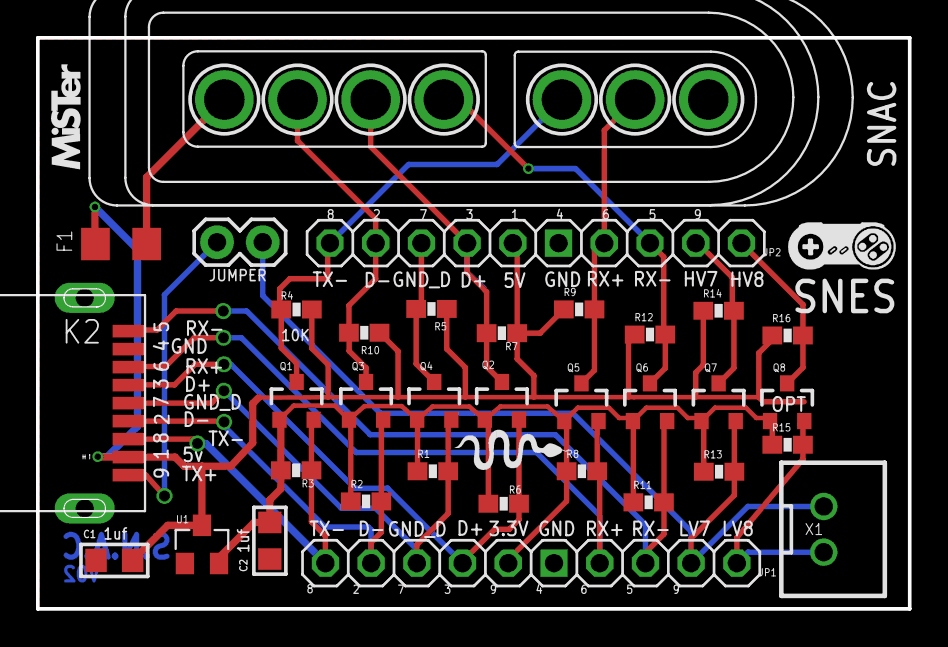
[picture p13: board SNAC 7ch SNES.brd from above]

Board: 2 copper layers, 48.4 x 31.7 mm, 34 parts (0 on the bottom side), 21 nets.

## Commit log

2020-11-23 Added version with SMS 3D Glasses driver + DB9
    [SNAC 7ch SMS DB9 3D.brd, SNAC 7ch SMS DB9 3D.sch]
2020-12-07 Added combined voltage translation + SNES joyport
    [SNAC 7ch SMS DB9 3D.brd, SNAC 7ch SMS DB9 3D.sch, SNAC 7ch SNES.brd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]
2020-12-07 Add PCB images and other details to the README
2020-12-07 Add PNG files for PCB pics
2020-12-07 Added ver. with JST XH and SNES joypad, for plastic housing
    [SNAC 7ch SNES in Housing.brd, SNAC 7ch SNES in Housing.sch, SNAC 7ch SNES.brd]
2020-12-09 Add Compact SNES version, and WIP SNES Multitap
    [SNAC 7ch SNES in Housing - Compact.brd, SNAC 7ch SNES in Housing - Compact.sch, SNAC 7ch SNES in Housing - Multitap.brd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]
2020-12-09 Added minimal SNES ver, with JST for USER IO. And SMS 3D Dongle
    [SNAC 7ch SMS 3D Dongle.brd, SNAC 7ch SMS 3D Dongle.sch, SNAC 7ch SNES in Housing - Minimal with JST.brd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]
2020-12-09 Changed SMS 3D Dongle back to using LV7 on USER IO
    [SNAC 7ch SMS 3D Dongle.brd, SNAC 7ch SMS 3D Dongle.sch, SNAC 7ch SNES in Housing - Minimal with JST.brd]
2020-12-13 SMS 3D and SNES SNAC JST updates
    [SNAC 7ch SMS 3D Dongle.brd, SNAC 7ch SMS 3D Dongle.sch, SNAC 7ch SNES in Housing - Minimal with JST.brd]
2020-12-23 added reversed JST footprint to SNES SNAC Minimal
    [SNAC 7ch SNES in Housing - Minimal with JST.brd, SNAC 7ch SNES in Housing - Minimal with JST.sch]
2020-12-24 Added SMS with 3D glasses driver, JST version
    [SNAC 7ch SMS DB9 3D in Housing with JST.brd, SNAC 7ch SMS DB9 3D in Housing with JST.sch]
2020-12-24 Updated SMS DB9 with JST version, and PCB image
    [SNAC 7ch SMS DB9 3D in Housing with JST.brd, SNAC 7ch SMS DB9 3D in Housing with JST.sch]
2021-02-04 changed from LV7 to LV5 pin, for the 3D Glasses boards
    [SNAC 7ch SMS 3D Dongle.brd, SNAC 7ch SMS 3D Dongle.sch, SNAC 7ch SMS DB9 3D.brd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]
2021-02-04 changed from LV7 to LV5 pin on the DB9 3D with JST design
    [SNAC 7ch SMS DB9 3D in Housing with JST.brd, SNAC 7ch SMS DB9 3D in Housing with JST.sch]
2021-02-12 removed the Compact, TXS chip, and SMS3D with USB3 plug versions
    [SNAC 7ch SMS 3D Dongle.brd, SNAC 7ch SMS 3D Dongle.sch, SNAC 7ch SMS DB9 3D.brd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]
2021-02-12 Updated PCB images and README
    [SNAC 7ch SMS 3D Dongle.brd]
2021-02-12 Added missing PCB images
2021-02-13 Added charge pump to the SMS 3D and SMS DB9 3D PCBs
    [SNAC 7ch SMS 3D Dongle.brd, SNAC 7ch SMS 3D Dongle.sch, SNAC 7ch SMS DB9 3D in Housing with JST.brd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]
2021-02-13 Fixed bottom layer ground pour on SMS 3D Dongle. Updated BOM
    [SNAC 7ch SMS 3D Dongle.brd]
2021-03-13 Changed to a MAX660 charge pump on the JST DB9 3D Glasses board
    [SNAC 7ch SMS 3D Dongle.brd, SNAC 7ch SMS DB9 3D in Housing with JST.brd, SNAC 7ch SMS DB9 3D in Housing with JST.sch]
2021-03-13 SMS 3D dongle charge pump and BOM updated
    [SNAC 7ch SMS 3D Dongle.brd, SNAC 7ch SMS 3D Dongle.sch]
2021-03-13 Removed unneeded diode from the SMS 3D dongle + BOM
    [SNAC 7ch SMS 3D Dongle.brd, SNAC 7ch SMS 3D Dongle.sch]
2021-03-13 Moved the SNES conn on the JST version to better fit the eBay case
    [SNAC 7ch SMS DB9 3D in Housing with JST.sch, SNAC 7ch SNES in Housing - Minimal with JST.brd]
2021-03-18 XOR Osc on 3D boards needed an extra resistor
    [SNAC 7ch SMS 3D Dongle.brd, SNAC 7ch SMS 3D Dongle.sch, SNAC 7ch SMS DB9 3D in Housing with JST.brd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]
2021-04-16 New SMS DB9 3D JST rev + BOM done
    [SNAC 7ch SMS DB9 3D in Housing with JST.brd]
2021-04-26 removed one cap from the SNES SNAC JST, as it was overkill
    [SNAC 7ch SNES in Housing - Minimal with JST.brd, SNAC 7ch SNES in Housing - Minimal with JST.sch]
2021-05-03 Updated the BOM for the SMS DB9 3D for digikey. Parts were out-of-stock etc.
2021-05-04 fixed major screw-up with the USERIO/JST pinout. Removed the unused FET
    [SNAC 7ch SMS DB9 3D in Housing with JST.brd, SNAC 7ch SMS DB9 3D in Housing with JST.sch]
2021-06-11 slight tidy of SMS DB9 3D board
    [SNAC 7ch SMS DB9 3D in Housing with JST.brd, SNAC 7ch SMS DB9 3D in Housing with JST.sch]
2021-06-15 LV6/LV7 selection jumper added to SMS 3D board
    [SNAC 7ch SMS DB9 3D in Housing with JST.brd, SNAC 7ch SMS DB9 3D in Housing with JST.sch]
2021-06-15 Added note to SMS 3D board about USB 3.0 wire colour swaps
    [SNAC 7ch SMS DB9 3D in Housing with JST.sch]

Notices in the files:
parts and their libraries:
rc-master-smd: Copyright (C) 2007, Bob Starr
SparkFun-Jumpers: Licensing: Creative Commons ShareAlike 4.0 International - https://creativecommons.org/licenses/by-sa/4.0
